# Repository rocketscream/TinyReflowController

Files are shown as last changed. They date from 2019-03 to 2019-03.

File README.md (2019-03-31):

# Tiny Reflow Controller
An all-in-one Arduino compatible reflow controller powered by ATmega328P (V2) or ATtiny1634R (V1). A reincarnation of the Reflow Oven Controller Shield that requires an external Arduino board like Arduino Uno based on user feedbacks over the years. Powered by the ATmega328P/ATtiny1634R coupled with the latest thermocouple sensor interface IC MAX31856 from Maxim, we managed to remove the need of an Arduino board and reduce the overall cost. We also use as much SMD parts in this revision to keep the cost low (manual soldering and left over residue cleaning is time consuming) and leaving only the terminal block and the LCD connector on through hole version. We also managed to streamline all components to run on 3.3V to further simplify the design. All you need is an external Solid State Relay (SSR) (rated accordingly to your oven), K type thermocouple (we recommend those with fiber glass or steel jacket), and an oven of course! You can now select to run a lead-free profile or leaded profile from the selection switch. V2 comes with 0.96" 128*64 OLED LCD to plot the real-time reflow curve and has a built-in serial-USB interface. V2 also has an optional transistor output drive fan if needed.

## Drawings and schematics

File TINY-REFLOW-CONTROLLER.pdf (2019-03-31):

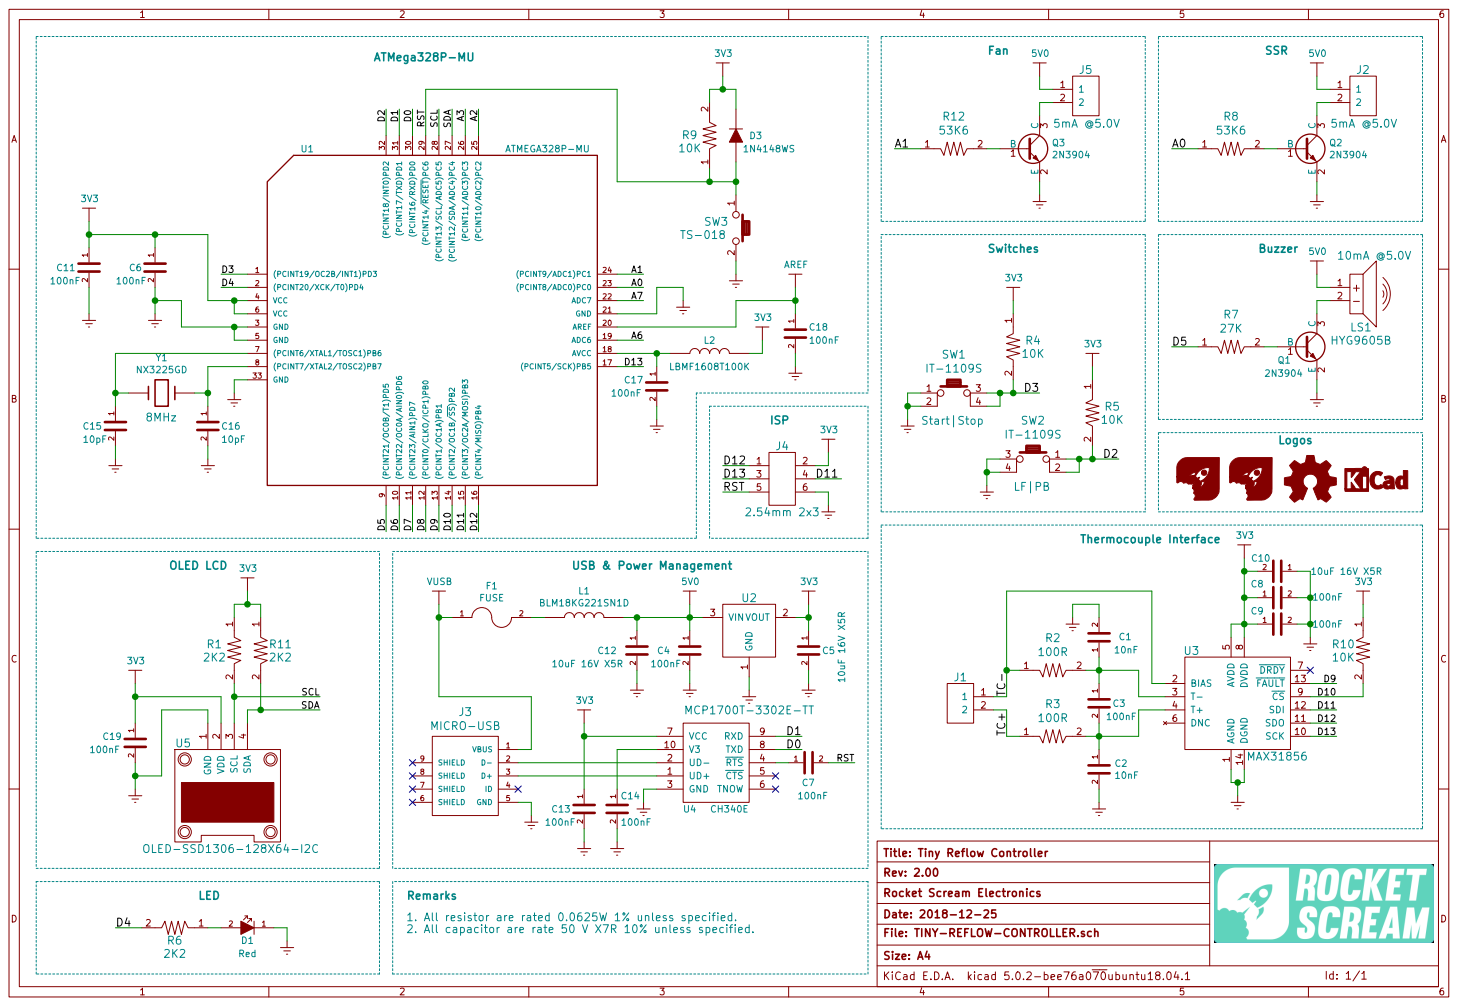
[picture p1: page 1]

1 VOUT 2 VIN 3 U2 MCP1700T-3302E-TT D2 Fan

Buzzer USB & Power Management

1 SCK 10 SDO 11 SDI 12 FAULT 13 DGND 14 BIAS 2 T- 3 T+ 4 AVDD

Id: 1/1 Title: Tiny Reflow Controller File: TINY-REFLOW-CONTROLLER.sch Rocket Scream Electronics
D Date: 2018-12-25 KiCad E.D.A. kicad 5.0.2-bee76a070ubuntu18.04.1 Rev: 2.00 Size: A4

1. All resistor are rated 0.0625W 1% unless specified.
2. All capacitor are rate 50 V X7R 10% unless specified.

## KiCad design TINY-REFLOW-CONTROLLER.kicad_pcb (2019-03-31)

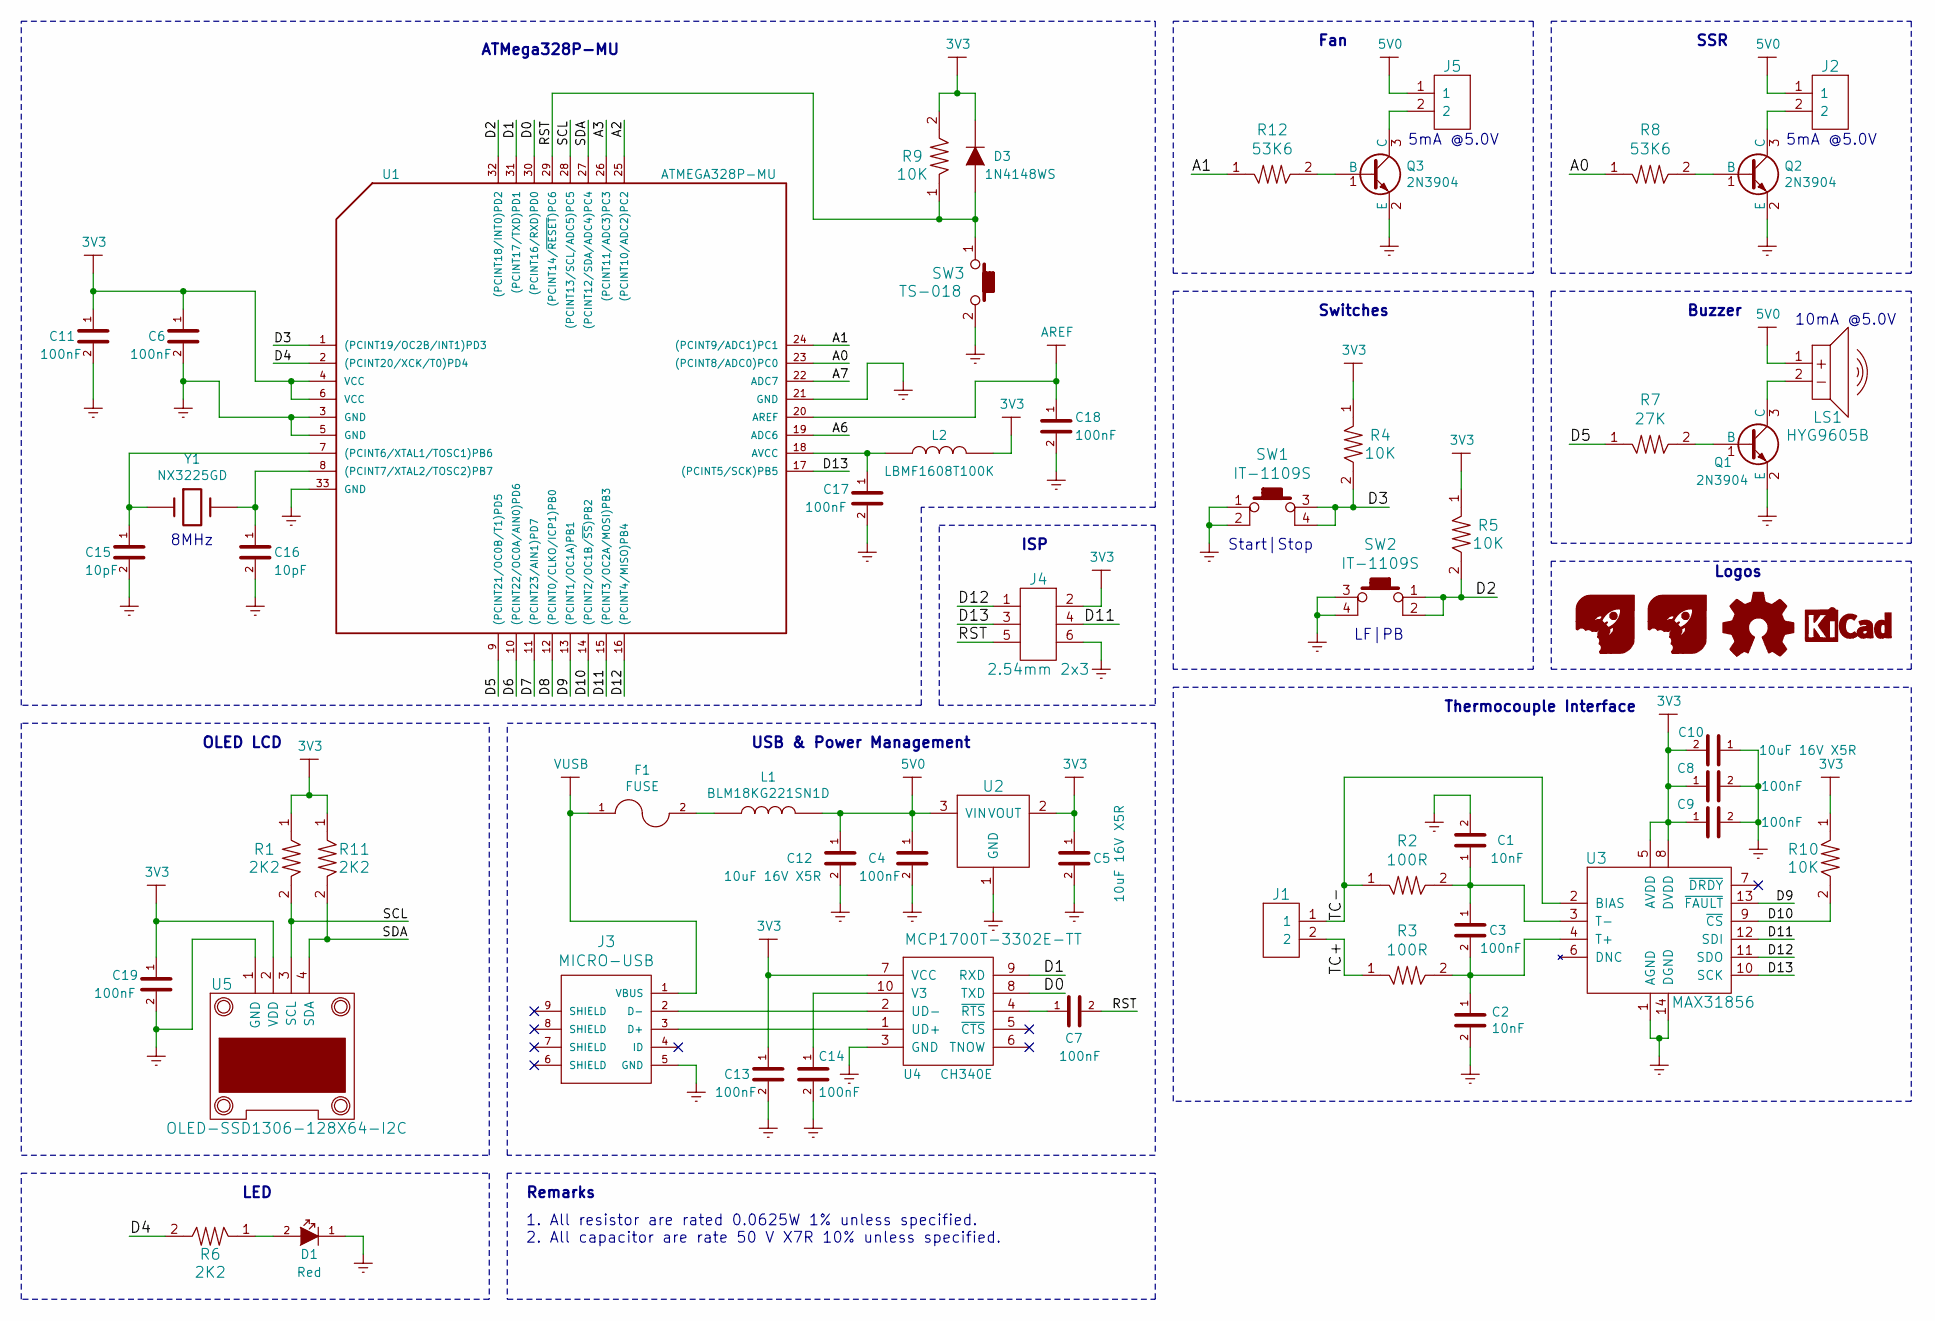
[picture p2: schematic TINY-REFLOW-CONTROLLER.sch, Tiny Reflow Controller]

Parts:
C1, C2: 10nF; C_0603
C3, C4, C6, C7, C8, C9, C11, C13, C14, C17, C18, C19: 100nF; C_0603
C5, C10, C12: 10uF 16V X5R; C_0603
C15, C16: 10pF; C_0603
D1: Red; LED_0603
D3: 1N4148WS; SOD-323
F1: FUSE; MF-FSMF
J1, J2, J5: TERMINAL-BLOCK-1x2; TB-1776275-2
J3: MICRO-USB
J4: 2.54mm 2x3; HDR_2x3_Pitch2.54mm
L1: BLM18KG221SN1D; I_0603
L2: LBMF1608T100K; I_0603
LOGO1: LOGO-ROCKET-SCREAM; LOGO-ROCKET-SCREAM_Without_Text_XXXSmall
LOGO2: LOGO-KICAD; LOGO-KICAD_XSmall
LOGO3: LOGO-ROCKET-SCREAM; LOGO-ROCKET-SCREAM_Vertical_Small
LOGO4: LOGO-OSHW; LOGO-OSHW_Small
LS1: HYG9605B
Q1, Q2, Q3: 2N3904; SOT-23
R1, R6, R11: 2K2; R_0603
R2, R3: 100R; R_0603
R4, R5, R9, R10: 10K; R_0603
R7: 27K; R_0603
R8, R12: 53K6; R_0603
SW1, SW2: IT-1109S; IT-1102W
SW3: TS-018
U1: ATMEGA328P-MU; QFN-32_5x5mm_Pitch0.5mm
U2: MCP1700T-3302E-TT; SOT-23
U3: MAX31856; TSSOP-14
U4: CH340E; MSOP-10
U5: OLED-SSD1306-128X64-I2C
Y1: NX3225GD

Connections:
3V3: C5.1, C6.1, C8.1, C9.1, C10.2, C11.1, C13.1, C19.1, D3.1 (K), J4.2, L2.2, R1.1, R4.1, R5.1, R9.2, R10.1, R11.1, U1.4 (VCC), U1.6 (VCC), U2.2 (VOUT), U3.5 (AVDD), U3.8 (DVDD), U4.7 (VCC), U5.2 (VDD)
5V0: C4.1, C12.1, J2.1, J5.1, L1.2, LS1.1, U2.3 (VIN)
/A0: R8.1, U1.23 ((PCINT8/ADC0)PC0)
/A1: R12.1, U1.24 ((PCINT9/ADC1)PC1)
/A2: U1.25 ((PCINT10/ADC2)PC2)
/A3: U1.26 ((PCINT11/ADC3)PC3)
/A6: U1.19 (ADC6)
/A7: U1.22 (ADC7)
/D0: U1.30 ((PCINT16/RXD)PD0), U4.8 (TXD)
/D1: U1.31 ((PCINT17/TXD)PD1), U4.9 (RXD)
/D2: R5.2, SW2.1, SW2.2, U1.32 ((PCINT18/INT0)PD2)
/D3: R4.2, SW1.3, SW1.4, U1.1 ((PCINT19/OC2B/INT1)PD3)
/D4: R6.2, U1.2 ((PCINT20/XCK/T0)PD4)
/D5: R7.1, U1.9 ((PCINT21/OC0B/T1)PD5)
/D6: U1.10 ((PCINT22/OC0A/AIN0)PD6)
/D7: U1.11 ((PCINT23/AIN1)PD7)
/D8: U1.12 ((PCINT0/CLKO/ICP1)PB0)
/D9: U1.13 ((PCINT1/OC1A)PB1), U3.13 (~FAULT~)
/D10: R10.2, U1.14 ((PCINT2/OC1B/~SS~)PB2), U3.9 (~CS~)
/D11: J4.4, U1.15 ((PCINT3/OC2A/MOSI)PB3), U3.12 (SDI)
/D12: J4.1, U1.16 ((PCINT4/MISO)PB4), U3.11 (SDO)
/D13: J4.3, U1.17 ((PCINT5/SCK)PB5), U3.10 (SCK)
/RST: C7.2, D3.2 (A), J4.5, R9.1, SW3.1, U1.29 ((PCINT14/~RESET~)PC6)
/SCL: R1.2, U1.28 ((PCINT13/SCL/ADC5)PC5), U5.3 (SCL)
/SDA: R11.2, U1.27 ((PCINT12/SDA/ADC4)PC4), U5.4 (SDA)
/TC+: J1.2, R3.1
/TC-: J1.1, R2.1, U3.2 (BIAS)
AREF: C18.1, U1.20 (AREF)
GND: C1.2, C2.2, C4.2, C5.2, C6.2, C8.2, C9.2, C10.1, C11.2, C12.2, C13.2, C14.2, C15.2, C16.2, C17.2, C18.2, C19.2, D1.1 (K), J3.5 (GND), J4.6, Q1.2 (E), Q2.2 (E), Q3.2 (E), SW1.1, SW1.2, SW2.3, SW2.4, SW3.2, U1.3 (GND), U1.5 (GND), U1.21 (GND), U1.33 (GND), U2.1 (GND), U3.1 (AGND), U3.14 (DGND), U4.3 (GND), U5.1 (GND)
unnamed: C1.1, C3.1, R2.2, U3.3 (T-)
unnamed: C2.1, C3.2, R3.2, U3.4 (T+)
unnamed: C7.1, U4.4 (~RTS~)
unnamed: C14.1, U4.10 (V3)
unnamed: C15.1, U1.7 ((PCINT6/XTAL1/TOSC1)PB6), Y1.1
unnamed: C16.1, U1.8 ((PCINT7/XTAL2/TOSC2)PB7), Y1.2
unnamed: C17.1, L2.1, U1.18 (AVCC)
unnamed: D1.2 (A), R6.1
unnamed: F1.2, L1.1
unnamed: J2.2, Q2.3 (C)
unnamed: J3.2 (D-), U4.2 (UD-)
unnamed: J3.3 (D+), U4.1 (UD+)
unnamed: J5.2, Q3.3 (C)
unnamed: LS1.2, Q1.3 (C)
unnamed: Q1.1 (B), R7.2
unnamed: Q2.1 (B), R8.2
unnamed: Q3.1 (B), R12.2
VUSB: F1.1, J3.1 (VBUS)

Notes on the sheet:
10mA @5.0V
5mA @5.0V
Logos
Switches
SSR
LED
Buzzer
USB & Power Management
ATMega328P-MU
Thermocouple Interface
ISP
OLED LCD
Remarks
1. All resistor are rated 0.0625W 1% unless specified. 2. All capacitor are rate 50 V X7R 10% unless specified.
Start|Stop
LF|PB
8MHz
Fan

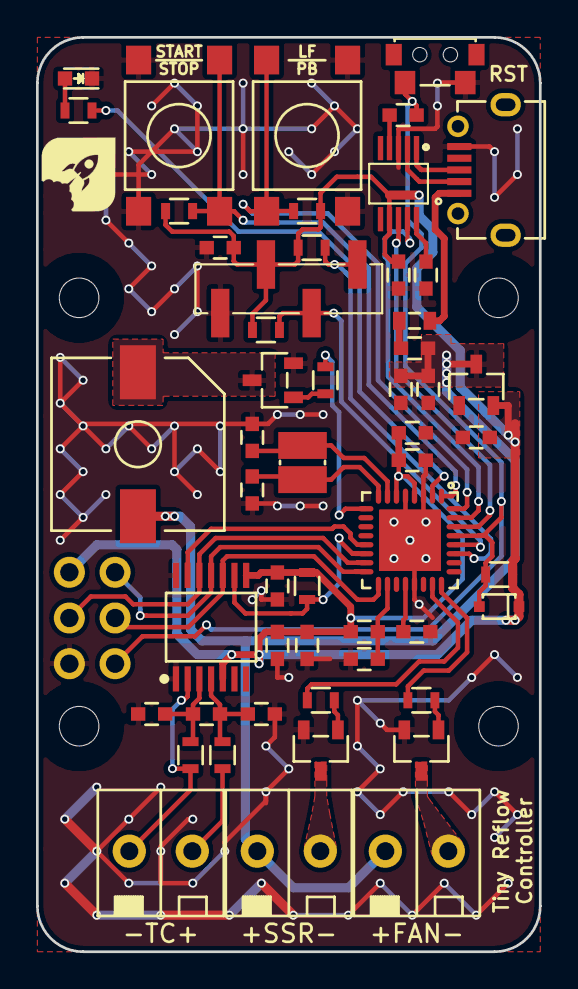
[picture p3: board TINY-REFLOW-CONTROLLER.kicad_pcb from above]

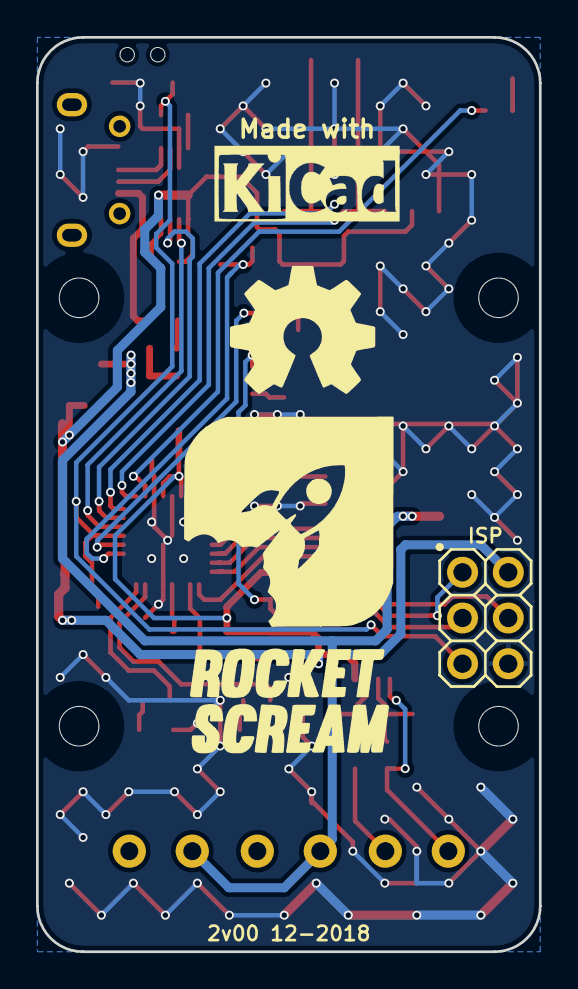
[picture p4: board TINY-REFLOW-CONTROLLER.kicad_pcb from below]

Board: 2 copper layers, 27.9 x 50.8 mm, 58 parts (4 on the bottom side), 40 nets.

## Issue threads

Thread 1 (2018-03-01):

Require nightly build Kicad to open.

dwhacks, 2018-03-01:
I'm on Linux Mint, and when trying to open the schematic file in kicad it says my version is to old! I have the "newest" stable, which leads me to believe this was made in a nightly (which gave me issues when I tried nightlies a year ago).

Any chance we could get Gerbers, or even an oshpark shared project?

rocketscream, 2018-03-02:
Hi @dwhacks,

Yes, it is indeed designed in nightly builds (couldn't stop myself). I just added the gerber files in latest commit of 69a41e7. I no longer use OSHPark service (last used close to 5 years ago), so I'm not sure how the settings (like the silkscreen minimum line thickness, edge copper distance limit) would affect the board produced. But, board was designed with 10 mil minimum track and 10 mil minimum clearance except the ATtiny1634R QFN chip (I believe it needs 8 mil clearance in between pads).

dwhacks, 2018-03-02:
Thanks! That mostly works, except for the slots in the USB connector, but thats not a big deal. Any chance you could post up a BOM too? Or should I just wait for the finished boards to be in stock again at rocketscream?

I guess I could install a nightly kicad on a different machine... But maybe this will benefit others too?

Closed 2018-03-04.

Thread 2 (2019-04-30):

Controller gets stuck at preheat stage

fifteenhex, 2019-04-30:
My controller worked once but now it's starting the preheat stage according to the screen, the temp gets up to ~148c, it starts turning the elements on and off to hold that temperature and then does nothing else. The graph shows it holding that temperature for a few minutes and it never jumps into the soak stage.

I can adjust the preheat min value so that it goes into soak at 148c instead but I think there should be some sort of timer to abort the whole process if a stage takes too long.

rocketscream, 2019-04-30:
This is due to the oven unable to retain the heat. Try insulating the oven a little and usually that helps.

But, a very good point on the timer. Will implement it on the next firmware release.

fifteenhex, 2019-05-02:
I'll try adding some more insulation.
If I get time I'll implement a timer that aborts the reflow process if it takes too long and send you a PR.

Closed 2019-05-02.

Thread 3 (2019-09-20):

[Suggestion]

gitfve, 2019-09-20:
-Hints-
*In the setup, set filter to MAX31856_NOISE_FILTER_50HZ or ..._60HZ you newer use the filter?
*Updating display every 100ms, why? It is real time heavy...
*Reading sensor every 1000ms? Must be more often for to get PID more accurate
*Code clean up, and use some function and not so many Global vars:-(
--
*Option to select more profiles 1..10
*Option to select the 50/60HZ filter.
*Option to set some PID values.
---

rocketscream, 2019-09-23:
> In the setup, set filter to MAX31856_NOISE_FILTER_50HZ or ..._60HZ you newer use the filter?
This is good suggestion. I'll check whether the Adafruit MAX31856 library has this enabled. If not, I will do a pull first.

> Updating display every 100ms, why? It is real time heavy...
It was initially set at a lower rate during development stage. But, as it is a human interface, whenever a human presses a button or an error occurs, user expect instant visual feedback on the display. Refreshing it slower will let the user think the button presses are not working and other visual feedback issue.

> Reading sensor every 1000ms? Must be more often for to get PID more accurate
Yes, we do not need to sample that fast. In previous version it was even sampled once per second. But, for simplicity with the UI refresh rate, it was set same as the display refresh rate. It doesn't do any harm sampling any faster too.

> Code clean up, and use some function and not so many Global vars:-(
Please suggest which variable that can be further improved into a local variable. And do a pull request.

> Option to select more profiles 1..10
> Option to select the 50/60HZ filter.
> Option to set some PID values.
Not sure whether any more profiles is of any use as most user just want to reflow either a leaded or lead free. The filter option is good and as explained above. Tweaking the PID values is great but it will open up a whole bigger cans of issues later (user might tweak it wrongly, oven not responding as expected, profile goes off, etc). You can always use the default values and tweak it from there.

One of the objective of the controller is to be simple and does what it needs to do: reflow.

Teknost, 2020-04-15:
Additional profiles for 3D printer filament drying would be awesome.  i.e. straight baking for a few hours at 40C or 80C.

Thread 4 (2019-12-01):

Suggestion: add 'bake parts'

a7hybnj2, 2019-12-01:
Provide an option to BAKE parts. When working with SMD parts many need to be kept at a specific moisture level and if it ever goes over you have to bake the parts for a long time to make them 'safe' to reflow again.

I have already modified mine to provide this option but my code isn't very clean so I will not submit it.

I used this link for basic part handling, storage, and baking times.

https://armprojects.wordpress.com/2018/02/18/moisture-sensitivity-of-smd-components-and-pcbs/

ctravisc, 2019-12-09:
Care to share your less than ideal code with with someone who couldn’t tell anyway? 🥴

Could be a very useful feature.

a7hybnj2, 2019-12-27:
@ctravisc since it requires the oven to be on for LONG durations  the likely hood of the operator walking away while it is running is very high. Which means the probability of you burning your home or office down goes up. I don't really want anything to do with that especially since my code is dirty.

I did not use PID I only did (in pseudo):
```
while time < duration
If temp < bakeTemp - 5
  heater on
if temp >= bakeTemp
  heater off
```

Teknost, 2020-04-15:
This would also be good to make the machine serve as a 3D printer filament dryer.

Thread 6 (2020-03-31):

cool stage problem

ton4eff, 2020-03-31:
After the "REFLOW_STATE_COOL", it continues to work, keeping the "TEMPERATURE_COOL_MIN" for ever ( 100C for example), instead to continue to "REFLOW_STATUS_OFF". I don't know why. Sometimes I forget to push stop button and it is very annoying. Also the fan part in the code is missing and not working.

It wold be great if there was a timer for preheat stage also, as it is for soak stage. With higher power ovens it heats too fast...

richardklingler, 2020-05-20:
Same here...

Always stops around the 520th reading:

520,100.00,113.50,0.00

Even this part is not executed then anymore I added for debugging:

if (millis() > nextRead)
{
  Serial.println("input");
}

richardklingler, 2020-05-20:
Problem seems to be solved...

As I use a display with higher resolution the variable x should be defined as unsigned int instead of unsigned char...otherwise during drawing the temp graph the controller locks up and hangs forever.

The graph drawing code is anyway too blown up with unnecessary chunk...
but this might have to the original display...all is cleared and then everything is redrawn..whereas a regular SPI TFT only the status message, the temperature and one pixel for the graph would have to be drawn (o;

Now it stopped here on the serial output, as it should be with the door closed:

612,100.00,100.00,0.00

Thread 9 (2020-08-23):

millis() function hangs oled

unbracedcat500, 2020-08-23:
Hello,
I've noticed the IF statement _(if millis() > buzzerPeriod)_  in case **REFLOW_STATE_COMPLETE** hangs the OLED. Even after pressing RESET button or re uploading the code, the OLED remains in the previous state(NO ADAFRUIT LOGO appears). Is it okay if I use delay function instead of millis to turn ON the buzzer?

rocketscream, 2020-08-24:
It shouldn't, it's just a check whether the time has lapsed. I have never seen it hang until today at that stage. You can't use delay because we need to stay in that state while servicing other processes (read sensor, update OLED). Using delay means blocking those processes.

VILLO88, 2020-11-15:
i am having the same problems, has anyone found a solution?

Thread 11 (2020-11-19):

please help!

VILLO88, 2020-11-19:
Hi, i am trying to reproduce the controller V2 on breadboard with an arduino pro mini @3v,8mhz and the other components(128x64oled,buttons, max31856 etc..) , code is uploaded without problems but oled not working until i reduce screen height to 32 and temperature reading say "nan" all the time.
The funny thing is, without changing anything in the wiring, if i try to load the test firmware for the max31856 and for the ssd1306 from the libraries examples sketch..both work without problems.
The only way to get the oled working on 128x64 is to delete everything in the void loop under
// If switch 1 is pressed
  if (switchStatus == SWITCH_1)
  {
the temperature reading still say nan..i really do not understand why..

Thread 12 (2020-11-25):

reflowOvenPID.Compute();    issue

VILLO88, 2020-11-25:
Hi, i'm trying to running this code from Rocketscream tiny reflow V2, but when the Compute() call is in the loop, simply the board do not boot up, the oled stay black and nothing works, if i temporarly remove the compute() using // the board is booting and oled works. ANy idea?
p.s. i use the original board from rocketscream, the 328p have promini3v3 8mhz bootloader on it.
----
-----
------

  // PID computation and SSR control
  if (reflowStatus == REFLOW_STATUS_ON)
  {
    now = millis();

    reflowOvenPID.Compute();                                                            THIS IS THE FUNCTION CALL !!!

    if ((now - windowStartTime) > windowSize)
    {
      // Time to shift the Relay Window
      windowStartTime += windowSize;
    }
    if (output > (now - windowStartTime)) digitalWrite(ssrPin, HIGH);
    else digitalWrite(ssrPin, LOW);
  }
  // Reflow oven process is off, ensure oven is off
  else
  {
    digitalWrite(ssrPin, LOW);
  }

rocketscream, 2020-11-27:
Did you add anything onto the code? It looks like not enough RAM? I have been producing boards few days ago and never run into something like this.

VILLO88, 2020-11-27:
Thanks for the reply, no i did not add anything to the code, very strange, i ve tried to make a new clean installation of arduino ide and libraries but nothing change.
I use this atmega with Promini 3v3 8mhz bootloader
https://www.mouser.it/ProductDetail/Microchip-Technology-Atmel/ATMEGA328P-MU?qs=K8BHR703ZXgI55tOEPBx9w%3D%3D

2 photo of my pcb :
https://gyazo.com/ee13fb30e90581852b786eca3ec4063f
https://gyazo.com/249481c18296b7385a7ea8863f741651

Any idea? i really love this project, i hope to find a solution

rocketscream, 2020-11-28:
The MCU is correct part number. The compute part shouldn't be blocking. I'm not sure what causes this because this is the first time I heard something like this on this design.

jone1316, 2021-02-11:
I had the exact same issue. I solved it by using using an older version of the arduino PID library (version 1.1.1).
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

Hope this helps.

rocketscream, 2021-02-11:
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

Thank you for reporting this. A look into the PID library changes, it shouldn't hold the process. I believe it could be the RAM issue on the ATMega328P. I will check on this. I'm using 1.1.1 for your information.

VILLO88, 2021-02-11:
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

I will try, thank you very much!

jone1316, 2021-02-12:
It was version 1.2.0 that was causing an issue.
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

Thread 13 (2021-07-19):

A referencing issue?

Engineer817, 2021-07-19:
Hi, I just finished my oven build and ran a few tests. I decided to change some of the PID settings on the device, but when I tried to upload the code the screen would not turn on.
Very long story short, I hacked my way into finding that the OLED hangs on the line timerSoak = millis() + soakMicroPeriod; inside both the case REFLOW_STATE_PREHEAT and the case REFLOW_STATE_SOAK.
I decided to replace the soakMicroPeriod variable with the hard 9000 value for leadfree (what I am using currently) and the screen now turns on, although I haven't tested it in the oven yet.
I don't think the millis is hanging the system like other posts are saying, but there might be some referencing issue going on.
In addition the oled now has an area which is constantly pixiliating at the bottom right corner of the screen.

rocketscream, 2021-07-20:
If you are using V2 of the PID library, it will overrun the amount of RAM on the ATMega328P, hence it stop at the screen routine. Please use V1 of the PID library.

Engineer817, 2021-07-20:
Hi, I double checked and I am using the V1.2 PID library linked in the .ino.

RyanJBeagles, 2021-07-22:
Another update: you were correct, it was the V1.2 library causing the issue. Despite setting the library to 1.1 in the manage libraries menu, the compiler still selected the newer library after it found 2 compatible libraries available. I deleted the 1.2 library out of the folder leaving the compiler only one choice and things seem to be working properly again.

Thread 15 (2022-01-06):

Crashes with updated libraries (Clarify required library versions in docs)

z-l-p, 2022-01-06:
I just spent hours trying to compile the V2 code in 2021 (Arduino IDE 1.8.9). Much has changed since 2019, and compiling with current library versions will result in a crashed Arduino (no display at startup, etc). Most open issues seem to be traceable to this.
My solution was to look back through the releases of all required libraries to find the ones that were contemporary in March 2019 when the initial commit was made. I had success with the versions below. (Others might work too, but I got tired of trying.)

- Arduino PID Library: v1.1.1
- Adafruit MAX31856 Library: v1.0.3
- Adafruit SSD1306 Library: v1.2.9
- Adafruit GFX Library: v1.4.8

NOTE: The Arduino IDE library manager doesn't seem to roll back to previous versions gracefully. It's best to delete the folders for any existing versions before using the library manager to download the old versions.

Maybe lib version requirements could be added to the README or the code comments?

szlovak, 2022-09-06:
What I have found out also is , that PID settings are totally different from these that are already loaded in FW that comes with board. I wanted only to shorten default values , reflow was too fast in my oven. After loading sketch nothing matches what was before.

clytle374, 2024-04-06:
I've been playing with this code(forking it) and I believe the 328P is running out of memory crashing the display memory allocation.  Removing some code left me with a glitching lower right corner of the display.   Moving to a atmega644 fixed it.  I can't be sure of all issues as I'm using a different thermocouple chip.

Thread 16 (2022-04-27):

Just THANK YOU!

homonto, 2022-04-27:
I have bought the small (100x100mm) hot plate heater, removed the original controller (it was only capable to set the desired temperature and it kept it there) and used your code with ESP32 to do the job - almost no changes - only LCD out as I tested it without any screen.
My first impression is: AMAZING!
I will also put ILI9341 display with some more buttons or so (or rotary encoder) or even the touch version of ILIILI9341 - the graphic library will take some time but ok.

But what I am most amazed with: your PID settings did the job almost without tweaking. My first PCB done and dusted.

So: THANK YOU again!

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

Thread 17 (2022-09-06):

INO sketch doesn't work on ATMEGA328P version

szlovak, 2022-09-06:
I thought I bricked my unit, but luckily I have downloaded with PICKIT4 to a hex file before doing anything. My board is described as:
2v00 12-2018 ,  E488074    ,   JDB-D    ,   94V-0

In arduino IDE 1.8.13 it stared to compile, on the newest it didn't. Then I loaded sketch file from this GIT and only thing it does is initial beep, nothing on LCD.

szlovak, 2022-09-06:
I read sticky comment , that I didn't see in the first place, now it works.

Closed 2022-09-06.

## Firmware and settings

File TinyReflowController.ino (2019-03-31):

/*******************************************************************************
  Title: Tiny Reflow Controller
  Version: 2.00
  Date: 03-03-2019
  Company: Rocket Scream Electronics
  Author: Lim Phang Moh
  Website: www.rocketscream.com

  Brief
  =====
  This is an example firmware for our Arduino compatible Tiny Reflow Controller.
  A big portion of the code is copied over from our Reflow Oven Controller
  Shield. We added both lead-free and leaded reflow profile support in this
  firmware which can be selected by pressing switch #2 (labelled as LF|PB on PCB)
  during system idle. The unit will remember the last selected reflow profile.
  You'll need to use the MAX31856 library for Arduino.

  Lead-Free Reflow Curve
  ======================

  Temperature (Degree Celcius)                 Magic Happens Here!
  245-|                                               x  x
      |                                            x        x
      |                                         x              x
      |                                      x                    x
  200-|                                   x                          x
      |                              x    |                          |   x
      |                         x         |                          |       x
      |                    x              |                          |
  150-|               x                   |                          |
      |             x |                   |                          |
      |           x   |                   |                          |
      |         x     |                   |                          |
      |       x       |                   |                          |
      |     x         |                   |                          |
      |   x           |                   |                          |
  30 -| x             |                   |                          |
      |<  60 - 90 s  >|<    90 - 120 s   >|<       90 - 120 s       >|
      | Preheat Stage |   Soaking Stage   |       Reflow Stage       | Cool
   0  |_ _ _ _ _ _ _ _|_ _ _ _ _ _ _ _ _ _|_ _ _ _ _ _ _ _ _ _ _ _ _ |_ _ _ _ _
                                                                 Time (Seconds)

  Leaded Reflow Curve (Kester EP256)
  ==================================

  Temperature (Degree Celcius)         Magic Happens Here!
  219-|                                       x  x
      |                                    x        x
      |                                 x              x
  180-|                              x                    x
      |                         x    |                    |   x
      |                    x         |                    |       x
  150-|               x              |                    |           x
      |             x |              |                    |
      |           x   |              |                    |
      |         x     |              |                    |
      |       x       |              |                    |
      |     x         |              |                    |
      |   x           |              |                    |
  30 -| x             |              |                    |
      |<  60 - 90 s  >|<  60 - 90 s >|<   60 - 90 s      >|
      | Preheat Stage | Soaking Stage|   Reflow Stage     | Cool
   0  |_ _ _ _ _ _ _ _|_ _ _ _ _ _ _ |_ _ _ _ _ _ _ _ _ _ |_ _ _ _ _ _ _ _ _ _ _
                                                                 Time (Seconds)

  This firmware owed very much on the works of other talented individuals as
  follows:
  ==========================================
  Brett Beauregard (www.brettbeauregard.com)
  ==========================================
  Author of Arduino PID library. On top of providing industry standard PID
  implementation, he gave a lot of help in making this reflow oven controller
  possible using his awesome library.

  ==========================================
  Limor Fried of Adafruit (www.adafruit.com)
  ==========================================
  Author of Arduino MAX31856 and SSD1306 libraries. Adafruit has been the source 
  of tonnes of tutorials, examples, and libraries for everyone to learn.

  ==========================================
  Spence Konde (www.drazzy.com/e/)
  ==========================================
  Maintainer of the ATtiny core for Arduino:
  https://github.com/SpenceKonde/ATTinyCore

  Disclaimer
  ==========
  Dealing with high voltage is a very dangerous act! Please make sure you know
  what you are dealing with and have proper knowledge before hand. Your use of
  any information or materials on this Tiny Reflow Controller is entirely at
  your own risk, for which we shall not be liable.

  Licences
  ========
  This Tiny Reflow Controller hardware and firmware are released under the
  Creative Commons Share Alike v3.0 license
  http://creativecommons.org/licenses/by-sa/3.0/
  You are free to take this piece of code, use it and modify it.
  All we ask is attribution including the supporting libraries used in this
  firmware.

  Required Libraries
  ==================
  - Arduino PID Library:
    >> https://github.com/br3ttb/Arduino-PID-Library
  - Adafruit MAX31856 Library:
    >> https://github.com/adafruit/Adafruit_MAX31856
  - Adafruit SSD1306 Library:
    >> https://github.com/adafruit/Adafruit_SSD1306
  - Adafruit GFX Library:
    >> https://github.com/adafruit/Adafruit-GFX-Library

  Revision  Description
  ========  ===========
  2.00      Support V2 of the Tiny Reflow Controller:
            - Based on ATMega328P 3.3V @ 8MHz
            - Uses SSD1306 128x64 OLED
  1.00      Initial public release:
            - Based on ATtiny1634R 3.3V @ 8MHz
            - Uses 8x2 alphanumeric LCD

*******************************************************************************/

// ***** INCLUDES *****
#include <SPI.h>
#include <Wire.h>
#include <EEPROM.h>
#include <LiquidCrystal.h>
#include <Adafruit_GFX.h>      // Comment for VERSION 1
#include <Adafruit_SSD1306.h>  // Comment for VERSION 1 
#include <Adafruit_MAX31856.h> 
#include <PID_v1.h>

// ***** TYPE DEFINITIONS *****
typedef enum REFLOW_STATE
{
  REFLOW_STATE_IDLE,
  REFLOW_STATE_PREHEAT,
  REFLOW_STATE_SOAK,
  REFLOW_STATE_REFLOW,
  REFLOW_STATE_COOL,
  REFLOW_STATE_COMPLETE,
  REFLOW_STATE_TOO_HOT,
  REFLOW_STATE_ERROR
} reflowState_t;

typedef enum REFLOW_STATUS
{
  REFLOW_STATUS_OFF,
  REFLOW_STATUS_ON
} reflowStatus_t;

typedef	enum SWITCH
{
  SWITCH_NONE,
  SWITCH_1,
  SWITCH_2
} switch_t;

typedef enum DEBOUNCE_STATE
{
  DEBOUNCE_STATE_IDLE,
  DEBOUNCE_STATE_CHECK,
  DEBOUNCE_STATE_RELEASE
} debounceState_t;

typedef enum REFLOW_PROFILE
{
  REFLOW_PROFILE_LEADFREE,
  REFLOW_PROFILE_LEADED
} reflowProfile_t;

// ***** CONSTANTS *****
// ***** GENERAL *****
#define VERSION 2 // Replace with 1 or 2

// ***** GENERAL PROFILE CONSTANTS *****
#define PROFILE_TYPE_ADDRESS 0
#define TEMPERATURE_ROOM 50
#define TEMPERATURE_SOAK_MIN 150
#define TEMPERATURE_COOL_MIN 100
#define SENSOR_SAMPLING_TIME 1000
#define SOAK_TEMPERATURE_STEP 5

// ***** LEAD FREE PROFILE CONSTANTS *****
#define TEMPERATURE_SOAK_MAX_LF 200
#define TEMPERATURE_REFLOW_MAX_LF 250
#define SOAK_MICRO_PERIOD_LF 9000

// ***** LEADED PROFILE CONSTANTS *****
#define TEMPERATURE_SOAK_MAX_PB 180
#define TEMPERATURE_REFLOW_MAX_PB 224
#define SOAK_MICRO_PERIOD_PB 10000

// ***** SWITCH SPECIFIC CONSTANTS *****
#define DEBOUNCE_PERIOD_MIN 100

// ***** DISPLAY SPECIFIC CONSTANTS *****
#define UPDATE_RATE 100

// ***** PID PARAMETERS *****
// ***** PRE-HEAT STAGE *****
#define PID_KP_PREHEAT 100
#define PID_KI_PREHEAT 0.025
#define PID_KD_PREHEAT 20
// ***** SOAKING STAGE *****
#define PID_KP_SOAK 300
#define PID_KI_SOAK 0.05
#define PID_KD_SOAK 250
// ***** REFLOW STAGE *****
#define PID_KP_REFLOW 300
#define PID_KI_REFLOW 0.05
#define PID_KD_REFLOW 350
#define PID_SAMPLE_TIME 1000

#if VERSION == 2
#define SCREEN_WIDTH 128 // OLED display width, in pixels
#define SCREEN_HEIGHT 64 // OLED display height, in pixels
#define X_AXIS_START 18 // X-axis starting position
#endif

// ***** LCD MESSAGES *****
const char* lcdMessagesReflowStatus[] = {
  "Ready",
  "Pre",
  "Soak",
  "Reflow",
  "Cool",
  "Done!",
  "Hot!",
  "Error"
};

// ***** DEGREE SYMBOL FOR LCD *****
unsigned char degree[8]  = {
  140, 146, 146, 140, 128, 128, 128, 128
};

// ***** PIN ASSIGNMENT *****
#if VERSION == 1
unsigned char ssrPin = 3;
unsigned char thermocoupleCSPin = 2;
unsigned char lcdRsPin = 10;
unsigned char lcdEPin = 9;
unsigned char lcdD4Pin = 8;
unsigned char lcdD5Pin = 7;
unsigned char lcdD6Pin = 6;
unsigned char lcdD7Pin = 5;
unsigned char buzzerPin = 14;
unsigned char switchPin = A1;
unsigned char ledPin = LED_BUILTIN;
#elif VERSION == 2
unsigned char ssrPin = A0;
unsigned char fanPin = A1;
unsigned char thermocoupleCSPin = 10;
unsigned char ledPin = 4;
unsigned char buzzerPin = 5;
unsigned char switchStartStopPin = 3;
unsigned char switchLfPbPin = 2;
#endif

// ***** PID CONTROL VARIABLES *****
double setpoint;
double input;
double output;
double kp = PID_KP_PREHEAT;
double ki = PID_KI_PREHEAT;
double kd = PID_KD_PREHEAT;
int windowSize;
unsigned long windowStartTime;
unsigned long nextCheck;
unsigned long nextRead;
unsigned long updateLcd;
unsigned long timerSoak;
unsigned long buzzerPeriod;
unsigned char soakTemperatureMax;
unsigned char reflowTemperatureMax;
unsigned long soakMicroPeriod;
// Reflow oven controller state machine state variable
reflowState_t reflowState;
// Reflow oven controller status
reflowStatus_t reflowStatus;
// Reflow profile type
reflowProfile_t reflowProfile;
// Switch debounce state machine state variable
debounceState_t debounceState;
// Switch debounce timer
long lastDebounceTime;
// Switch press status
switch_t switchStatus;
switch_t switchValue;
switch_t switchMask;
// Seconds timer
unsigned int timerSeconds;
// Thermocouple fault status
unsigned char fault;
#ifdef VERSION == 2
unsigned int timerUpdate;
unsigned char temperature[SCREEN_WIDTH - X_AXIS_START];
unsigned char x;
#endif

// PID control interface
PID reflowOvenPID(&input, &output, &setpoint, kp, ki, kd, DIRECT);
#if VERSION == 1
// LCD interface
LiquidCrystal lcd(lcdRsPin, lcdEPin, lcdD4Pin, lcdD5Pin, lcdD6Pin, lcdD7Pin);
#elif VERSION == 2
Adafruit_SSD1306 oled(SCREEN_WIDTH, SCREEN_HEIGHT, &Wire);
#endif
// MAX31856 thermocouple interface
Adafruit_MAX31856 thermocouple = Adafruit_MAX31856(thermocoupleCSPin);

void setup()
{
  // Check current selected reflow profile
  unsigned char value = EEPROM.read(PROFILE_TYPE_ADDRESS);
  if ((value == 0) || (value == 1))
  {
    // Valid reflow profile value
    reflowProfile = value;
  }
  else
  {
    // Default to lead-free profile
    EEPROM.write(PROFILE_TYPE_ADDRESS, 0);
    reflowProfile = REFLOW_PROFILE_LEADFREE;
  }

  // SSR pin initialization to ensure reflow oven is off
  digitalWrite(ssrPin, LOW);
  pinMode(ssrPin, OUTPUT);

  // Buzzer pin initialization to ensure annoying buzzer is off
  digitalWrite(buzzerPin, LOW);
  pinMode(buzzerPin, OUTPUT);

  // LED pins initialization and turn on upon start-up (active high)
  pinMode(ledPin, OUTPUT);
  digitalWrite(ledPin, HIGH);

  // Initialize thermocouple interface
  thermocouple.begin();
  thermocouple.setThermocoupleType(MAX31856_TCTYPE_K);

  // Start-up splash
  digitalWrite(buzzerPin, HIGH);
#if VERSION == 1
  lcd.begin(8, 2);
  lcd.createChar(0, degree);
  lcd.clear();
  lcd.print(F(" Tiny  "));
  lcd.setCursor(0, 1);
  lcd.print(F(" Reflow "));
#elif VERSION == 2
  oled.begin(SSD1306_SWITCHCAPVCC, 0x3C);
  oled.display();
#endif
  digitalWrite(buzzerPin, LOW);
  delay(2000);
#if VERSION == 1
  lcd.clear();
  lcd.print(F(" v1.00  "));
  lcd.setCursor(0, 1);
  lcd.print(F("26-07-17"));
  delay(2000);
  lcd.clear();
#elif VERSION == 2
  oled.clearDisplay();
  oled.setTextSize(1);
  oled.setTextColor(WHITE);
  oled.setCursor(0, 0);
  oled.println(F("     Tiny Reflow"));
  oled.println(F("     Controller"));
  oled.println();
  oled.println(F("       v2.00"));
  oled.println();
  oled.println(F("      04-03-19"));
  oled.display();
  delay(3000);
  oled.clearDisplay();
#endif

  // Serial communication at 115200 bps
  Serial.begin(115200);

  // Turn off LED (active high)
  digitalWrite(ledPin, LOW);
  // Set window size
  windowSize = 2000;
  // Initialize time keeping variable
  nextCheck = millis();
  // Initialize thermocouple reading variable
  nextRead = millis();
  // Initialize LCD update timer
  updateLcd = millis();
}

void loop()
{
  // Current time
  unsigned long now;

  // Time to read thermocouple?
  if (millis() > nextRead)
  {
    // Read thermocouple next sampling period
    nextRead += SENSOR_SAMPLING_TIME;
    // Read current temperature
    input = thermocouple.readThermocoupleTemperature();
    // Check for thermocouple fault
    fault = thermocouple.readFault();

    // If any thermocouple fault is detected
    if ((fault & MAX31856_FAULT_CJRANGE) ||
        (fault & MAX31856_FAULT_TCRANGE) ||
        (fault & MAX31856_FAULT_CJHIGH) ||
        (fault & MAX31856_FAULT_CJLOW) ||
        (fault & MAX31856_FAULT_TCHIGH) ||
        (fault & MAX31856_FAULT_TCLOW) ||
        (fault & MAX31856_FAULT_OVUV) ||
        (fault & MAX31856_FAULT_OPEN))
    {
      // Illegal operation
      reflowState = REFLOW_STATE_ERROR;
      reflowStatus = REFLOW_STATUS_OFF;
      Serial.println(F("Error"));
    }
  }

  if (millis() > nextCheck)
  {
    // Check input in the next seconds
    nextCheck += SENSOR_SAMPLING_TIME;
    // If reflow process is on going
    if (reflowStatus == REFLOW_STATUS_ON)
    {
      // Toggle red LED as system heart beat
      digitalWrite(ledPin, !(digitalRead(ledPin)));
      // Increase seconds timer for reflow curve plot
      timerSeconds++;
      // Send temperature and time stamp to serial
      Serial.print(timerSeconds);
      Serial.print(F(","));
      Serial.print(setpoint);
      Serial.print(F(","));
      Serial.print(input);
      Serial.print(F(","));
      Serial.println(output);
    }
    else
    {
      // Turn off red LED
      digitalWrite(ledPin, LOW);
    }
  }

  if (millis() > updateLcd)
  {
    // Update LCD in the next 100 ms
    updateLcd += UPDATE_RATE;
#if VERSION == 1
    // Clear LCD
    lcd.clear();
    // Print current system state
    lcd.print(lcdMessagesReflowStatus[reflowState]);
    lcd.setCursor(6, 0);
    if (reflowProfile == REFLOW_PROFILE_LEADFREE)
    {
	    lcd.print(F("LF"));
    }
    else
    {
      lcd.print(F("PB"));
    }
    lcd.setCursor(0, 1);
    
    // If currently in error state
    if (reflowState == REFLOW_STATE_ERROR)
    {
      // Thermocouple error (open, shorted)
      lcd.print(F("TC Error"));
    }
    else
    {
      // Display current temperature
      lcd.print(input);
#if ARDUINO >= 100
      // Display degree Celsius symbol
      lcd.write((uint8_t)0);
#else
      // Display degree Celsius symbol
      lcd.print(0, BYTE);
#endif
      lcd.print("C ");
    }
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

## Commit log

2017-09-11 Version 1.0
    [TINY-REFLOW-CONTROLLER-0R20.kicad_pcb, TINY-REFLOW-CONTROLLER-0R20.sch]
2018-03-02 Added gerber files
    [TINY-REFLOW-CONTROLLER.drl, TINY-REFLOW-CONTROLLER.gbl, TINY-REFLOW-CONTROLLER.gbo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]
2019-03-31 Version 2.0
    [TINY-REFLOW-CONTROLLER.drl, TINY-REFLOW-CONTROLLER.gbl, TINY-REFLOW-CONTROLLER.gbo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]
